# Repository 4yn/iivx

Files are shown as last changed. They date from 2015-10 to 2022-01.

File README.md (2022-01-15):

# iivx

> **Update 2022**
> 
> _Wow_ it's been a while.
> 
> Its been a bit over 6 years (maybe more by the time you're reading this) since I made this controller and the
> build log below. That also means there's that many years worth of newer projects and code out there for building
> music game controllers. Just to make it very clear, **most (if not all) of the code in this repository is outdated**
> and I highly recommend looking at some better/newer resources (code and build logs) if you are planning to try a
> similar project:
>
> - https://consandstuff.github.io/ (active community, especially recommend checking out the discord)
> - https://github.com/knuckleslee/RhythmCodes (will _probably_ work right out of the box)
> - https://rhythm-cons.wiki/w/Controller_Code (general purpose rhythm game controller code)
> - https://github.com/MHeironimus/ArduinoJoystickLibrary/ (general purpose joysticks code
> - https://github.com/speedypotato/Pico-Game-Controller (for the Pi Pico, I personally bought one)
>
> I'm glad that many people have found this repository useful. Keep making cool stuff!

Beatmania IIDX and Sound Voltex hybrid controller running on Arduino Due

Imgur album: http://imgur.com/a/iJoK6

Arduino DUE code targets arduino ver 1.6.4, 1.6.5 onwards added pluggable HID which breaks the SAM libraries

Arduino Leonardo code in /leoo/ targets arduino ver 1.6.8 but should work with versions upward of 1.6.5. /leoo/leoo/ contains code for 9 key + 9 led pnm controller, /leoo/leovx/ contains code for 7 key + 2 lq encoder (<=50ppr) voltex controller, /leoo/leohq/ contains code for 7 key + 2 hq encoder (>=50ppr) volltex controller.

## Variations

For a controller for both Lunatic Rave 2 and K-shoot mania at once (as seen in the youtube video), use a arduino DUE. Download the SAM core with version 1.6.4 and setup as seen in the Software section.

If you rather use a leonardo, you have 3 options:

- Controller with 9 buttons and 9 LEDs as seen in /leoo/leoo/
- Controller with 7 buttons and 2 low quality encoders as seen in /leoo/leovx/
- Controller with 7 buttons and 2 high quality encoders as seen in /leoo/leovxhq/

Just open the .ino file with the latest arudino version and download.

## Hardware

- Beatmania Buttons x9
  - Beatmania layout requires two rows of 3 and 4 vertical keys + 2 utility buttons
  - Voltex layout requires two rows of 4 and 2 (horizontal) keys + 1 utility button
  - Total 9 buttons, top row 3 vertical, middle row 4 vertical and bottom row 2 horizontal
  - [9x White Buttons purchased via Taobao, $10 SGD w/o shipping](https://item.taobao.com/item.htm?spm=a230r.1.14.22.b82vYR&id=15772881563&ns=1&abbucket=2#detail), [(Search Listings)](https://item.taobao.com/item.htm?spm=a230r.1.14.22.b82vYR&id=15772881563&ns=1&abbucket=2#detail)
    - One "button" comes with colored plunger, black main chassis with screw-threaded hollow shaft, accompanying nut for said shaft, extra rectangular housing for padding below, microswitch, microswitch LED saddle/chassis connector, LED housing and spring, all which are detachable
    - Replacing microswitches invloves pulling out microswitch saddle and replacing the microswitch
    - LEDs in the LED saddle may not all be same polarity, be sure to test and reverse LED polarity by pulling out and reinserting LED housing
    - Custom LEDs can also be used by replacing the LED in the housing with your own LEDs
    - LEDs are in theory rated for 12v, but the microcontroller can only supply 3.3v. Be sure to use a transistor or other power supply if you want full brightness.
- Rotary Encoders x3
  - Beatmania layout requires 1 turntable, KOCs use an optical encoder, but a rotary encoder is used here for consistency in purchasing
  - Voltex layout requires 2 knobs for VOL-L and VOL-R control
  - 24ppr encoders should suffice to give a resolution of 96 points per 360 degrees, but higher resolution encoders (300, 600 ppr) are accounted for in this project
  - [3x 600ppr Encoders purchased via Taobao, $25 SGD w/o shipping](http://world.taobao.com/item/16341987368.htm?spm=a312a.7700714.0.0.kKKUs0#detail), [(Search Listings)](http://world.taobao.com/search/search.htm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)
- Microcontroller
  - Arduino DUE used due to:
    - High clock rate
    - Interrupt capability on all pins (other Arduino boards only have 2-4 interrupt pins, insufficient for 4x reading of 3 different rotary encoders which need at least 6 interrupt pins)
    - Native USB functionality, custom HID descriptor is used via modifying core libraries (See Software Section)
  - Purchased a clone from Shenzhen Hua Qiang Bei, $20 SGD\
  - Other clones of DUE board should be readily purchasable online

### Misc Hardware

- Breadboard and jumper wire
- Crimp receptacles
  - Removable connectors which can be plugged in and out of microswitches on buttons
  - Eliminates need to solder directly onto microswitches, microswitches then can be easily replaced
  - One button needs 4 connections, 2 for the LED and 2 for the switch
  - Purchased from hardware store, [similar models here](http://sg.rs-online.com/web/c/connectors/terminals-splices/crimp-receptacles/)
  - Connections were made as such: Microswtich tab >(Crimp receptacle)> 20AUG wire >(soldering connection)> Jumper wire > Breadboard
  - Requires wire strippers, soldering kit and heat shrink tubing
- Logic level converters (if using high-precision encoders)
  - Arduino DUE runs at 3.3v logic, supplying 5v will (possibly) destroy the board
  - High precision encoders require 5v supply in order to function and will output square waves between 5v and 0v, which cannot be directly connected to the board
  - Data wires of each encoder pass through logic level converter to step down voltage, then are connected to the arduino board
  - Low precision encoders (sub 50 ppr) do NOT require a Vcc supply, hence can be read by connecting commmon pin to ground and data pins directly to the arduino board, then enabling the internal pull-up resistors
  - Alternatively just use a 10k and 20k resistor to create a voltage divider for each data wire for the encoder
  - [2x 4-channel Logic Level shifter from Adafruit, $10 SGD w/o shipping](https://www.adafruit.com/products/757)

## Building Materials

- Main mounting plate
  - Comprises
    - Holes for encoder shaft + screw holes to mount encoder
    - Holes for buttons
    - Holes for mounting other plates
  - CAD files are in [/cad/final/](/cad/final/) directory, file name "plate"
- Turntable
  - Round plate with hole in middle to fit rotary encoder shaft
  - Cad files are in /cad/final/ directory, file name "ring"
  - *WARNING: HOLE WAS DRAWN TOO SMALL FOR ENCODER, PLATE REQUIRED EXTRA MACHINING AFTER CNC MANUFACURING, WILL NOT WORK OUT OF THE BOX*
- Knobs
  - Knobs for VOL-L and VOL-R controls
  - [2x Aluminum HIFI Knobs purchased via Taobao, $8 SGD w/o shipping](http://world.taobao.com/item/10341449541.htm?spm=a312a.7700714.0.0.XBrOPF#detail)
  - Uses allen key to tighten, probably a 2-3M one
- Beams
  - Vertical beams to attach all other plates together
  - Similar design to 2020 extrusion for easy mounting of plates vertically
  - 3d printed, files available in [/skp/](/skp/) directory
  - Originally intended to have 6 beams, 3d printer malfunctioned halfway,
- Miscallaneous Plates
  - Extra plates, cut out of 5mm thick foam board. Other materials can be substituted
  - Bottom plate is 430mm x 190mm, with screw holes on four corners
  - Side plates are 398mm x 100mm
  - Cut using jigsaw
- Screws
  - 8x 4M self-tapping screws to attach main plate and bottom plate to beams
  - 9x 3M 12mm screws to mount rotary encoders
- Velcro/Dual-lock tape
  - Attach DUE to bottom plate, but remains detachable

## Assembly

1. Insert button through main plate and lock down with plastic nut
2. Wire buttons to breadboard
3. Screw on rotary encoders
4. Wire encoders to breadboard, including logic level shifter circuit
4. Screw on beams to main plate and then screw on bottom plate
5. Stick breadboard onto bottom plate using adhesive
6. Stick DUE onto bottom plate using velcro tape
7. Detach two beams and insert side plates, then reattach

## Software

The arduino DUE works out of the box with mouse and keyboard functionality, and modifying the USB core libraries allows modifications to how the DUE behaves as a HID object. Modified core library files are found at [/lib/USB/](/lib/usb/), replaces the files located at {APPDATA}\Local\Arduino15\packages\arduino\hardware\sam\1.6.4\cores\arduino\USB. Unmodified files are located at [/lib/USB backup/](/lib/USB%20backup/) to revert to keyboard and mouse functionality. This file implements a custom HID descriptor as well as methods to use said descriptor, allowing the DUE to be recognised as a "Game Pad" with 15 buttons, 3 analog axis and 11 Generic Indicators.

Once the custom USB libraries are installed, open iivx.ino and upload to the DUE.

## Wiring

iivx.ino uses the following pins:

| Item | Pin |
|---|-----|
| **Buttons** | |
| Btn 1 LED | 22  |
| Btn 1 Switch | 23  |
| Btn 2 LED | 24  |
| Btn 2 Switch | 25  |
| ... | ... |
| Btn 9 LED |  38 |
| Btn 9 Switch | 39  |
| **Encoders** | |
| VOL-L Enc Channel A | 46  |
| VOL-L Enc Channel B | 47  |
| VOL-R Enc Channel A | 48  |
| VOL-R Enc Channel B | 49  |
| Turntable Enc Channel A | 50  |
| Turntable Enc Channel B | 51  |

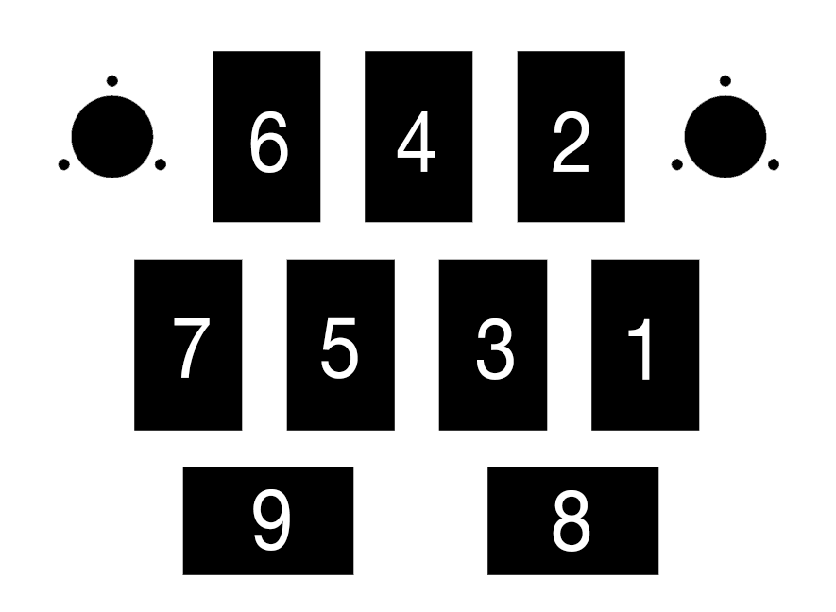
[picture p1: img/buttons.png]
Button Numbers


Button arrangement is up to you and can be changed by modifying the `buttonPins[]` and `ledPins[]` array. If you do change the buttons, be sure to change the constants in lines 178-185 of iivx.ino to correspond to suit your layout.

Getting the encoder arrangement correct is slightly more important. The encoder connected to pins 50 and 51 are given extra functionality in that clockwise and counter-clockwise rotation will trigger button presses on buttons 10 and 11, for use in bindings for Lunatic Rave 2. Additionally, changing the encoder pins requires not only changing the pin numbers in the `#define` lines, but also requires lookup on the exact register of the pin value. Reason being since the program accounts for high-resolution encoders, reading encoder state via digitalRead() has too much overhead which may result in dropped input from either encoder, whereas reading from the pin's memory address is much faster. Pins 64 to 51 all occupy the `PIOC` port on the DUE and the B channels corrsepond to the 16th, 14th and 12th bit of the PIOC memory value.

In order to change the pins the encoders are connected to, look up the exact port and bit that the pin corresponds to [here](http://www.robgray.com/temp/Due-pinout.svg). Change the pin numbers in `#define` as well as the `ENCODER_?_B_REGISTER` values.

## Usage

### Lighting

Press buttons 2, 6, 8 and 9 simultaneously, then finally press button

- 1 to disable LEDs
- 3 to enable reactive lighting, where pressing a button will light the corresponding LED
- 5 to enable HID lighting.

### Lunatic Rave 2

For buttons, bind as normal

For turntable, select turntable-left/right and then twist turntable accordingly

### K-Shoot Mania

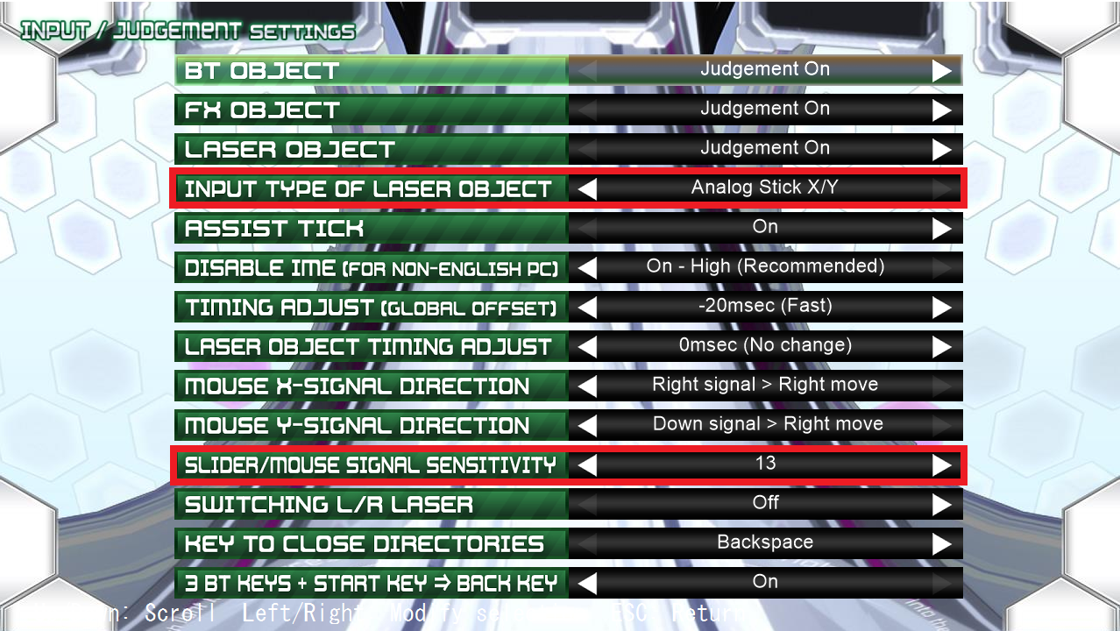
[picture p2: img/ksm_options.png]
KSM Options


Set Input Type to Analog Stick X/Y and set Signal Sensitivity to a high value (>10)

Test KSM play: https://youtu.be/374v2gmAJd4

TODO: In-Program Documentation

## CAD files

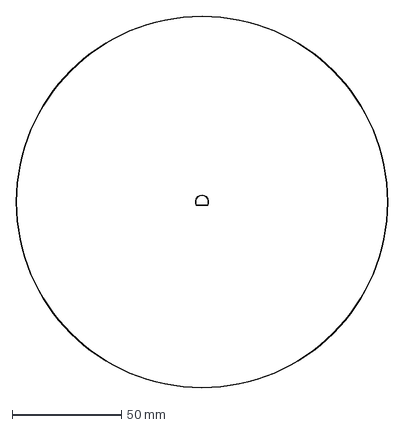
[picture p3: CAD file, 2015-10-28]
cad/final/ring.dxf
170.0 x 170.0 mm

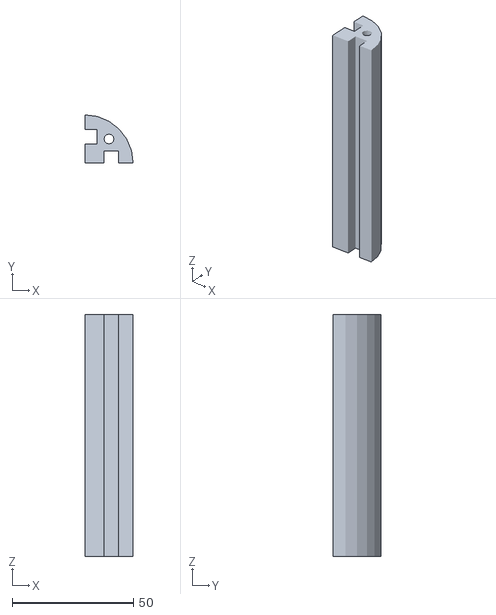
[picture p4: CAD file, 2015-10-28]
skp/edge.stl
20.0 x 20.0 x 100.0

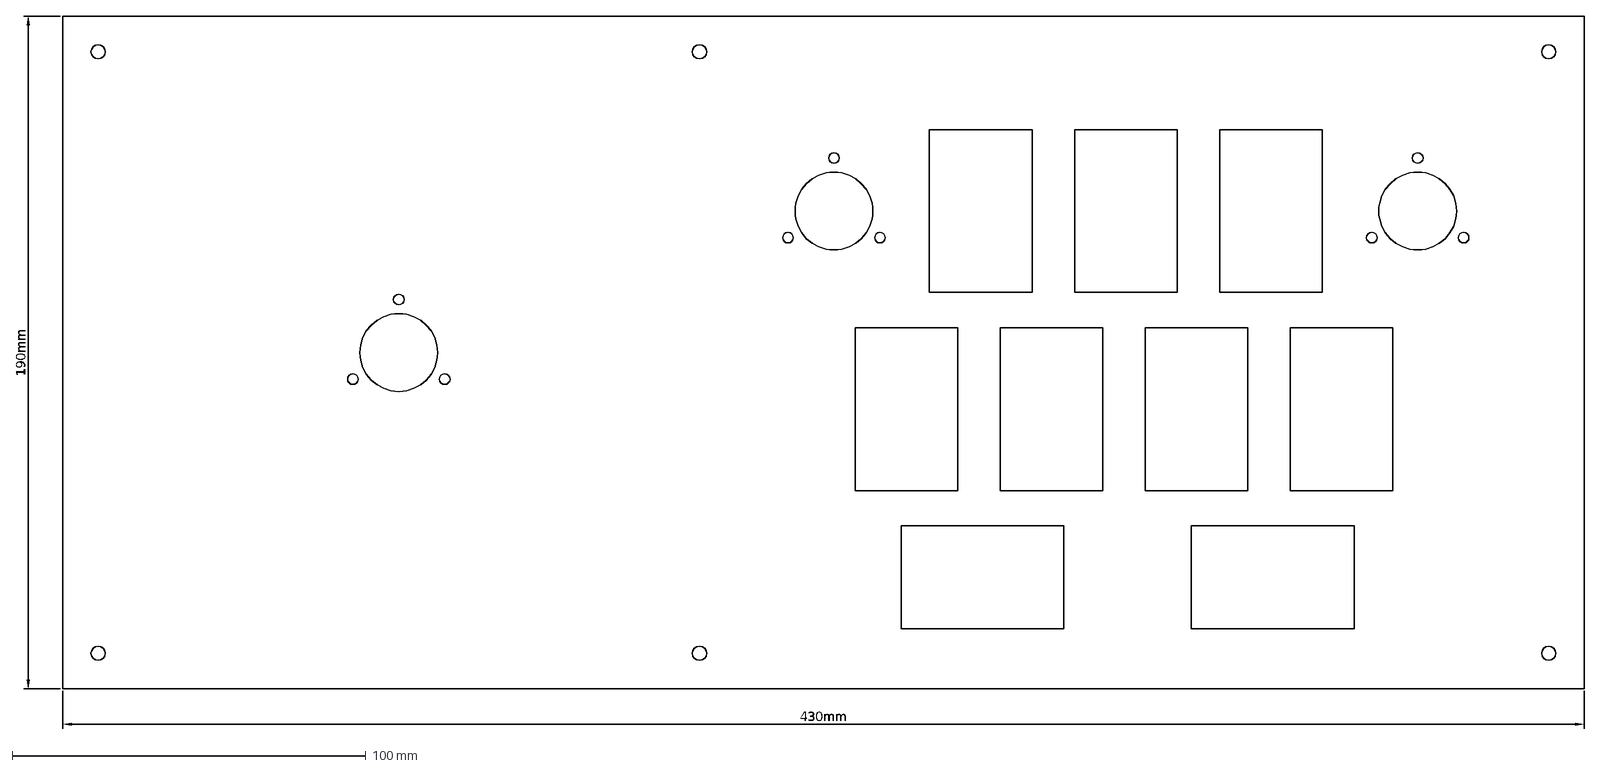
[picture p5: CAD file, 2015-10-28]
cad/final/plate.dxf
190mm
430mm

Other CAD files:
cad/sdvxc2.dwg
cad/sdvxc.dwg
skp/edge.skp

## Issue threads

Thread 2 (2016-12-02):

leovxhq:116: error: expected ')' before ';' token

Espionage724, 2016-12-02:
```
Arduino: 1.6.13 (Windows 10), Board: "Arduino Leonardo"

C:\Users\Espionage724\Desktop\arduino-1.6.13\arduino-builder -dump-prefs -logger=machine -hardware C:\Users\Espionage724\Desktop\arduino-1.6.13\hardware -tools C:\Users\Espionage724\Desktop\arduino-1.6.13\tools-builder -tools C:\Users\Espionage724\Desktop\arduino-1.6.13\hardware\tools\avr -built-in-libraries C:\Users\Espionage724\Desktop\arduino-1.6.13\libraries -libraries C:\Users\Espionage724\Documents\Arduino\libraries -fqbn=arduino:avr:leonardo -vid-pid=0X2341_0X8036 -ide-version=10613 -build-path C:\Users\ESPION~1\AppData\Local\Temp\arduino_build_766418 -warnings=none -prefs=build.warn_data_percentage=75 -prefs=runtime.tools.avr-gcc.path=C:\Users\Espionage724\Desktop\arduino-1.6.13\hardware\tools\avr -prefs=runtime.tools.avrdude.path=C:\Users\Espionage724\Desktop\arduino-1.6.13\hardware\tools\avr -verbose C:\Users\Espionage724\Downloads\iivx-master\leoo\leovxhq\leovxhq.ino
C:\Users\Espionage724\Desktop\arduino-1.6.13\arduino-builder -compile -logger=machine -hardware C:\Users\Espionage724\Desktop\arduino-1.6.13\hardware -tools C:\Users\Espionage724\Desktop\arduino-1.6.13\tools-builder -tools C:\Users\Espionage724\Desktop\arduino-1.6.13\hardware\tools\avr -built-in-libraries C:\Users\Espionage724\Desktop\arduino-1.6.13\libraries -libraries C:\Users\Espionage724\Documents\Arduino\libraries -fqbn=arduino:avr:leonardo -vid-pid=0X2341_0X8036 -ide-version=10613 -build-path C:\Users\ESPION~1\AppData\Local\Temp\arduino_build_766418 -warnings=none -prefs=build.warn_data_percentage=75 -prefs=runtime.tools.avr-gcc.path=C:\Users\Espionage724\Desktop\arduino-1.6.13\hardware\tools\avr -prefs=runtime.tools.avrdude.path=C:\Users\Espionage724\Desktop\arduino-1.6.13\hardware\tools\avr -verbose C:\Users\Espionage724\Downloads\iivx-master\leoo\leovxhq\leovxhq.ino
Using board 'leonardo' from platform in folder: C:\Users\Espionage724\Desktop\arduino-1.6.13\hardware\arduino\avr
Using core 'arduino' from platform in folder: C:\Users\Espionage724\Desktop\arduino-1.6.13\hardware\arduino\avr
Detecting libraries used...
"C:\Users\Espionage724\Desktop\arduino-1.6.13\hardware\tools\avr/bin/avr-g++" -c -g -Os -w -std=gnu++11 -fpermissive -fno-exceptions -ffunction-sections -fdata-sections -fno-threadsafe-statics  -flto -w -x c++ -E -CC -mmcu=atmega32u4 -DF_CPU=16000000L -DARDUINO=10613 -DARDUINO_AVR_LEONARDO -DARDUINO_ARCH_AVR  -DUSB_VID=0x2341 -DUSB_PID=0x8036 '-DUSB_MANUFACTURER="Unknown"' '-DUSB_PRODUCT="Arduino Leonardo"' "-IC:\Users\Espionage724\Desktop\arduino-1.6.13\hardware\arduino\avr\cores\arduino" "-IC:\Users\Espionage724\Desktop\arduino-1.6.13\hardware\arduino\avr\variants\leonardo" "C:\Users\ESPION~1\AppData\Local\Temp\arduino_build_766418\sketch\leovxhq.ino.cpp" -o "nul"
Using cached library dependencies for file: C:\Users\ESPION~1\AppData\Local\Temp\arduino_build_766418\sketch\HID.cpp
Using cached library dependencies for file: C:\Users\ESPION~1\AppData\Local\Temp\arduino_build_766418\sketch\iivx_leo.cpp
Generating function prototypes...
"C:\Users\Espionage724\Desktop\arduino-1.6.13\hardware\tools\avr/bin/avr-g++" -c -g -Os -w -std=gnu++11 -fpermissive -fno-exceptions -ffunction-sections -fdata-sections -fno-threadsafe-statics  -flto -w -x c++ -E -CC -mmcu=atmega32u4 -DF_CPU=16000000L -DARDUINO=10613 -DARDUINO_AVR_LEONARDO -DARDUINO_ARCH_AVR  -DUSB_VID=0x2341 -DUSB_PID=0x8036 '-DUSB_MANUFACTURER="Unknown"' '-DUSB_PRODUCT="Arduino Leonardo"' "-IC:\Users\Espionage724\Desktop\arduino-1.6.13\hardware\arduino\avr\cores\arduino" "-IC:\Users\Espionage724\Desktop\arduino-1.6.13\hardware\arduino\avr\variants\leonardo" "C:\Users\ESPION~1\AppData\Local\Temp\arduino_build_766418\sketch\leovxhq.ino.cpp" -o "C:\Users\ESPION~1\AppData\Local\Temp\arduino_build_766418\preproc\ctags_target_for_gcc_minus_e.cpp"
"C:\Users\Espionage724\Desktop\arduino-1.6.13\tools-builder\ctags\5.8-arduino10/ctags" -u --language-force=c++ -f - --c++-kinds=svpf --fields=KSTtzns --line-directives "C:\Users\ESPION~1\AppData\Local\Temp\arduino_build_766418\preproc\ctags_target_for_gcc_minus_e.cpp"
Compiling sketch...
Using previously compiled file: C:\Users\ESPION~1\AppData\Local\Temp\arduino_build_766418\sketch\HID.cpp.o
Using previously compiled file: C:\Users\ESPION~1\AppData\Local\Temp\arduino_build_766418\sketch\iivx_leo.cpp.o
"C:\Users\Espionage724\Desktop\arduino-1.6.13\hardware\tools\avr/bin/avr-g++" -c -g -Os -w -std=gnu++11 -fpermissive -fno-exceptions -ffunction-sections -fdata-sections -fno-threadsafe-statics -MMD -flto -mmcu=atmega32u4 -DF_CPU=16000000L -DARDUINO=10613 -DARDUINO_AVR_LEONARDO -DARDUINO_ARCH_AVR  -DUSB_VID=0x2341 -DUSB_PID=0x8036 '-DUSB_MANUFACTURER="Unknown"' '-DUSB_PRODUCT="Arduino Leonardo"' "-IC:\Users\Espionage724\Desktop\arduino-1.6.13\hardware\arduino\avr\cores\arduino" "-IC:\Users\Espionage724\Desktop\arduino-1.6.13\hardware\arduino\avr\variants\leonardo" "C:\Users\ESPION~1\AppData\Local\Temp\arduino_build_766418\sketch\leovxhq.ino.cpp" -o "C:\Users\ESPION~1\AppData\Local\Temp\arduino_build_766418\sketch\leovxhq.ino.cpp.o"
C:\Users\Espionage724\Downloads\iivx-master\leoo\leovxhq\leovxhq.ino: In function 'void loop()':

leovxhq:116: error: expected ')' before ';' token

         report.buttons &= ~((uint16_t)1 << (i+buttonCount);

                                                           ^

exit status 1
expected ')' before ';' token
```

4yn, 2016-12-02:
thanks

Closed 2016-12-02.

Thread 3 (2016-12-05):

leovxhq: 'iivxReport_t' does not name a type + Various "not declared in this scope" errors

Espionage724, 2016-12-05:
```
Arduino: 1.6.13 (Windows 7), Board: "Arduino/Genuino Uno"

C:\Users\Espionage724\Downloads\arduino-1.6.13-windows\arduino-1.6.13\arduino-builder -dump-prefs -logger=machine -hardware C:\Users\Espionage724\Downloads\arduino-1.6.13-windows\arduino-1.6.13\hardware -tools C:\Users\Espionage724\Downloads\arduino-1.6.13-windows\arduino-1.6.13\tools-builder -tools C:\Users\Espionage724\Downloads\arduino-1.6.13-windows\arduino-1.6.13\hardware\tools\avr -built-in-libraries C:\Users\Espionage724\Downloads\arduino-1.6.13-windows\arduino-1.6.13\libraries -libraries C:\Users\Espionage724\Documents\Arduino\libraries -fqbn=arduino:avr:uno -vid-pid=0X2341_0X8036 -ide-version=10613 -build-path C:\Users\ESPION~1\AppData\Local\Temp\arduino_build_732012 -warnings=none -prefs=build.warn_data_percentage=75 -prefs=runtime.tools.avrdude.path=C:\Users\Espionage724\Downloads\arduino-1.6.13-windows\arduino-1.6.13\hardware\tools\avr -prefs=runtime.tools.avr-gcc.path=C:\Users\Espionage724\Downloads\arduino-1.6.13-windows\arduino-1.6.13\hardware\tools\avr -verbose C:\Users\Espionage724\Downloads\iivx-master\leoo\leovxhq\leovxhq.ino
C:\Users\Espionage724\Downloads\arduino-1.6.13-windows\arduino-1.6.13\arduino-builder -compile -logger=machine -hardware C:\Users\Espionage724\Downloads\arduino-1.6.13-windows\arduino-1.6.13\hardware -tools C:\Users\Espionage724\Downloads\arduino-1.6.13-windows\arduino-1.6.13\tools-builder -tools C:\Users\Espionage724\Downloads\arduino-1.6.13-windows\arduino-1.6.13\hardware\tools\avr -built-in-libraries C:\Users\Espionage724\Downloads\arduino-1.6.13-windows\arduino-1.6.13\libraries -libraries C:\Users\Espionage724\Documents\Arduino\libraries -fqbn=arduino:avr:uno -vid-pid=0X2341_0X8036 -ide-version=10613 -build-path C:\Users\ESPION~1\AppData\Local\Temp\arduino_build_732012 -warnings=none -prefs=build.warn_data_percentage=75 -prefs=runtime.tools.avrdude.path=C:\Users\Espionage724\Downloads\arduino-1.6.13-windows\arduino-1.6.13\hardware\tools\avr -prefs=runtime.tools.avr-gcc.path=C:\Users\Espionage724\Downloads\arduino-1.6.13-windows\arduino-1.6.13\hardware\tools\avr -verbose C:\Users\Espionage724\Downloads\iivx-master\leoo\leovxhq\leovxhq.ino
Using board 'uno' from platform in folder: C:\Users\Espionage724\Downloads\arduino-1.6.13-windows\arduino-1.6.13\hardware\arduino\avr
Using core 'arduino' from platform in folder: C:\Users\Espionage724\Downloads\arduino-1.6.13-windows\arduino-1.6.13\hardware\arduino\avr
Detecting libraries used...
"C:\Users\Espionage724\Downloads\arduino-1.6.13-windows\arduino-1.6.13\hardware\tools\avr/bin/avr-g++" -c -g -Os -w -std=gnu++11 -fpermissive -fno-exceptions -ffunction-sections -fdata-sections -fno-threadsafe-statics  -flto -w -x c++ -E -CC -mmcu=atmega328p -DF_CPU=16000000L -DARDUINO=10613 -DARDUINO_AVR_UNO -DARDUINO_ARCH_AVR   "-IC:\Users\Espionage724\Downloads\arduino-1.6.13-windows\arduino-1.6.13\hardware\arduino\avr\cores\arduino" "-IC:\Users\Espionage724\Downloads\arduino-1.6.13-windows\arduino-1.6.13\hardware\arduino\avr\variants\standard" "C:\Users\ESPION~1\AppData\Local\Temp\arduino_build_732012\sketch\leovxhq.ino.cpp" -o "nul"
Using cached library dependencies for file: C:\Users\ESPION~1\AppData\Local\Temp\arduino_build_732012\sketch\HID.cpp
Using cached library dependencies for file: C:\Users\ESPION~1\AppData\Local\Temp\arduino_build_732012\sketch\iivx_leo.cpp
Generating function prototypes...
"C:\Users\Espionage724\Downloads\arduino-1.6.13-windows\arduino-1.6.13\hardware\tools\avr/bin/avr-g++" -c -g -Os -w -std=gnu++11 -fpermissive -fno-exceptions -ffunction-sections -fdata-sections -fno-threadsafe-statics  -flto -w -x c++ -E -CC -mmcu=atmega328p -DF_CPU=16000000L -DARDUINO=10613 -DARDUINO_AVR_UNO -DARDUINO_ARCH_AVR   "-IC:\Users\Espionage724\Downloads\arduino-1.6.13-windows\arduino-1.6.13\hardware\arduino\avr\cores\arduino" "-IC:\Users\Espionage724\Downloads\arduino-1.6.13-windows\arduino-1.6.13\hardware\arduino\avr\variants\standard" "C:\Users\ESPION~1\AppData\Local\Temp\arduino_build_732012\sketch\leovxhq.ino.cpp" -o "C:\Users\ESPION~1\AppData\Local\Temp\arduino_build_732012\preproc\ctags_target_for_gcc_minus_e.cpp"
"C:\Users\Espionage724\Downloads\arduino-1.6.13-windows\arduino-1.6.13\tools-builder\ctags\5.8-arduino10/ctags" -u --language-force=c++ -f - --c++-kinds=svpf --fields=KSTtzns --line-directives "C:\Users\ESPION~1\AppData\Local\Temp\arduino_build_732012\preproc\ctags_target_for_gcc_minus_e.cpp"
Compiling sketch...
Using previously compiled file: C:\Users\ESPION~1\AppData\Local\Temp\arduino_build_732012\sketch\HID.cpp.o
Using previously compiled file: C:\Users\ESPION~1\AppData\Local\Temp\arduino_build_732012\sketch\iivx_leo.cpp.o
"C:\Users\Espionage724\Downloads\arduino-1.6.13-windows\arduino-1.6.13\hardware\tools\avr/bin/avr-g++" -c -g -Os -w -std=gnu++11 -fpermissive -fno-exceptions -ffunction-sections -fdata-sections -fno-threadsafe-statics -MMD -flto -mmcu=atmega328p -DF_CPU=16000000L -DARDUINO=10613 -DARDUINO_AVR_UNO -DARDUINO_ARCH_AVR   "-IC:\Users\Espionage724\Downloads\arduino-1.6.13-windows\arduino-1.6.13\hardware\arduino\avr\cores\arduino" "-IC:\Users\Espionage724\Downloads\arduino-1.6.13-windows\arduino-1.6.13\hardware\arduino\avr\variants\standard" "C:\Users\ESPION~1\AppData\Local\Temp\arduino_build_732012\sketch\leovxhq.ino.cpp" -o "C:\Users\ESPION~1\AppData\Local\Temp\arduino_build_732012\sketch\leovxhq.ino.cpp.o"
leovxhq:2: error: 'iivxReport_t' does not name a type

 iivxReport_t report;

 ^

C:\Users\Espionage724\Downloads\iivx-master\leoo\leovxhq\leovxhq.ino: In function 'void loop()':

leovxhq:95: error: 'report' was not declared in this scope

       report.buttons |= (uint16_t)1 << i;

       ^

leovxhq:97: error: 'report' was not declared in this scope

       report.buttons &= ~((uint16_t)1 << i);

       ^

leovxhq:101: error: 'report' was not declared in this scope

   report.xAxis = (uint8_t)((int32_t)(encL / ENCODER_SENSITIVITY) % 256);

   ^

leovxhq:107: error: 'iivx_led' was not declared in this scope

     lights(iivx_led);

            ^

leovxhq:126: error: 'iivx' was not declared in this scope

   iivx.setState(&report);

   ^

exit status 1
'iivxReport_t' does not name a type
```

Espionage724, 2016-12-05:
Had the wrong board selected; no issues with compiling now.

Closed 2016-12-05.

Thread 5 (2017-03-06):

Wiring

croce3, 2017-03-06:
Hello, since i've no idea on how to wire and i fear to make a mess, could you please post a more in-depth wiring diagram?
Thanks in advance.

lizardbeans, 2017-07-20:
Hey, I'm not OP but I'll try to give you some wiring instructions.
From the Arduino there're pins for the buttons signal and for the LEDs energy (in simple words).
Each LED and Button have 2 metal connection points.
One of the is the signal and the other is a ground connection. Ground (a.k.a. common) can be a single wire that connects to each Ground metal connection.

You'll have something like this:

Button Signal     ------ goes to--------> Button pin on the Arduino
Button Ground  ------ goes to---------> Ground pin on the arduino

LED energy  ----------goes to---------> LED pin on the arduino
LED Ground ----------goes to---------> Ground pin on the arduino

You can take multiple grounds and put them together like this:

Button Signal >>> Button Pin 1
LED energy>>>>>LED Pin 1
Button Signal >>> Button Pin 2
LED energy>>>>>LED Pin 2
Button Signal >>> Button Pin 3
LED energy>>>>>LED Pin 3

Button 1 Ground>>>
Button 2 Ground>>>>>>
Button 3 Ground>>>>>>>>>
LED 1 Ground>>>>>>>>>>>>>> A single Ground pin.
LED 2 Ground>>>>>>>>>>>
LED 3 Ground>>>>>>>>

[Like this image](https://sdvxdiy.github.io/Pancake.io_files/switches.JPG)

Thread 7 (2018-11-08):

I got a strange issues？Or a wrong using?

pilldesomebody, 2018-11-08:
Arduino:1.8.7 (Windows 10), 开发板："Arduino Due (Programming Port)"

F:\Arduino\arduino-builder -dump-prefs -logger=machine -hardware F:\Arduino\hardware -hardware C:\Users\Barry zhou\AppData\Local\Arduino15\packages -tools F:\Arduino\tools-builder -tools F:\Arduino\hardware\tools\avr -tools C:\Users\Barry zhou\AppData\Local\Arduino15\packages -built-in-libraries F:\Arduino\libraries -libraries G:\documents\Arduino\libraries -fqbn=arduino:sam:arduino_due_x_dbg -ide-version=10807 -build-path C:\Users\BARRYZ~1\AppData\Local\Temp\arduino_build_538397 -warnings=none -build-cache C:\Users\BARRYZ~1\AppData\Local\Temp\arduino_cache_108794 -prefs=build.warn_data_percentage=75 -prefs=runtime.tools.bossac.path=C:\Users\Barry zhou\AppData\Local\Arduino15\packages\arduino\tools\bossac\1.3-arduino -prefs=runtime.tools.bossac-1.3-arduino.path=C:\Users\Barry zhou\AppData\Local\Arduino15\packages\arduino\tools\bossac\1.3-arduino -prefs=runtime.tools.arm-none-eabi-gcc.path=C:\Users\Barry zhou\AppData\Local\Arduino15\packages\arduino\tools\arm-none-eabi-gcc\4.8.3-2014q1 -prefs=runtime.tools.arm-none-eabi-gcc-4.8.3-2014q1.path=C:\Users\Barry zhou\AppData\Local\Arduino15\packages\arduino\tools\arm-none-eabi-gcc\4.8.3-2014q1 -verbose G:\download\Compressed\iivx\iivx.ino
F:\Arduino\arduino-builder -compile -logger=machine -hardware F:\Arduino\hardware -hardware C:\Users\Barry zhou\AppData\Local\Arduino15\packages -tools F:\Arduino\tools-builder -tools F:\Arduino\hardware\tools\avr -tools C:\Users\Barry zhou\AppData\Local\Arduino15\packages -built-in-libraries F:\Arduino\libraries -libraries G:\documents\Arduino\libraries -fqbn=arduino:sam:arduino_due_x_dbg -ide-version=10807 -build-path C:\Users\BARRYZ~1\AppData\Local\Temp\arduino_build_538397 -warnings=none -build-cache C:\Users\BARRYZ~1\AppData\Local\Temp\arduino_cache_108794 -prefs=build.warn_data_percentage=75 -prefs=runtime.tools.bossac.path=C:\Users\Barry zhou\AppData\Local\Arduino15\packages\arduino\tools\bossac\1.3-arduino -prefs=runtime.tools.bossac-1.3-arduino.path=C:\Users\Barry zhou\AppData\Local\Arduino15\packages\arduino\tools\bossac\1.3-arduino -prefs=runtime.tools.arm-none-eabi-gcc.path=C:\Users\Barry zhou\AppData\Local\Arduino15\packages\arduino\tools\arm-none-eabi-gcc\4.8.3-2014q1 -prefs=runtime.tools.arm-none-eabi-gcc-4.8.3-2014q1.path=C:\Users\Barry zhou\AppData\Local\Arduino15\packages\arduino\tools\arm-none-eabi-gcc\4.8.3-2014q1 -verbose G:\download\Compressed\iivx\iivx.ino
Using board 'arduino_due_x_dbg' from platform in folder: C:\Users\Barry zhou\AppData\Local\Arduino15\packages\arduino\hardware\sam\1.6.4
Using core 'arduino' from platform in folder: C:\Users\Barry zhou\AppData\Local\Arduino15\packages\arduino\hardware\sam\1.6.4
警告：库 SPI 中的分类 '' 不可用。设置为 'Uncategorized'
警告：库 Wire 中的分类 '' 不可用。设置为 'Uncategorized'
构建选项已变更，全部重新构建
警告：核心 'Arduino ARM (32-bits) Boards' 中的 platform.txt 文件 包含已废弃的 recipe.c.combine.pattern="{compiler.path}{compiler.c.elf.cmd}" {compiler.c.elf.flags} -mcpu={build.mcu} "-T{build.variant.path}/{build.ldscript}" "-Wl,-Map,{build.path}/{build.project_name}.map" {compiler.c.elf.extra_flags} -o "{build.path}/{build.project_name}.elf" "-L{build.path}" -mthumb -Wl,--cref -Wl,--check-sections -Wl,--gc-sections -Wl,--entry=Reset_Handler -Wl,--unresolved-symbols=report-all -Wl,--warn-common -Wl,--warn-section-align -Wl,--warn-unresolved-symbols -Wl,--start-group "{build.path}/syscalls_sam3.c.o" {object_files} "{build.variant.path}/{build.variant_system_lib}" "{build.path}/{archive_file}" -Wl,--end-group -lm -gcc，已自动转换为 recipe.c.combine.pattern="{compiler.path}{compiler.c.elf.cmd}" {compiler.c.elf.flags} -mcpu={build.mcu} "-T{build.variant.path}/{build.ldscript}" "-Wl,-Map,{build.path}/{build.project_name}.map" {compiler.c.elf.extra_flags} -o "{build.path}/{build.project_name}.elf" "-L{build.path}" -mthumb -Wl,--cref -Wl,--check-sections -Wl,--gc-sections -Wl,--entry=Reset_Handler -Wl,--unresolved-symbols=report-all -Wl,--warn-common -Wl,--warn-section-align -Wl,--warn-unresolved-symbols -Wl,--start-group "{build.path}/core/syscalls_sam3.c.o" {object_files} "{build.variant.path}/{build.variant_system_lib}" "{build.path}/{archive_file}" -Wl,--end-group -lm -gcc。请考虑更新核心。
警告：核心 'Arduino ARM (32-bits) Boards' 中的 platform.txt 文件 包含已废弃的 recipe.ar.pattern="{compiler.path}{compiler.ar.cmd}" {compiler.ar.flags} {compiler.ar.extra_flags} "{build.path}/{archive_file}" "{object_file}"，已自动转换为 recipe.ar.pattern="{compiler.path}{compiler.ar.cmd}" {compiler.ar.flags} {compiler.ar.extra_flags} "{archive_file_path}" "{object_file}"。请考虑更新核心。
Detecting libraries used...
"C:\\Users\\Barry zhou\\AppData\\Local\\Arduino15\\packages\\arduino\\tools\\arm-none-eabi-gcc\\4.8.3-2014q1/bin/arm-none-eabi-g++" -c -g -Os -w -ffunction-sections -fdata-sections -nostdlib -fno-threadsafe-statics --param max-inline-insns-single=500 -fno-rtti -fno-exceptions -Dprintf=iprintf -w -x c++ -E -CC -mcpu=cortex-m3 -DF_CPU=84000000L -DARDUINO=10807 -DARDUINO_SAM_DUE -DARDUINO_ARCH_SAM -D__SAM3X8E__ -mthumb -DUSB_VID=0x2341 -DUSB_PID=0x003e -DUSBCON "-DUSB_MANUFACTURER=\"Unknown\"" "-DUSB_PRODUCT=\"Arduino Due\"" "-IC:\\Users\\Barry zhou\\AppData\\Local\\Arduino15\\packages\\arduino\\hardware\\sam\\1.6.4\\system/libsam" "-IC:\\Users\\Barry zhou\\AppData\\Local\\Arduino15\\packages\\arduino\\hardware\\sam\\1.6.4\\system/CMSIS/CMSIS/Include/" "-IC:\\Users\\Barry zhou\\AppData\\Local\\Arduino15\\packages\\arduino\\hardware\\sam\\1.6.4\\system/CMSIS/Device/ATMEL/" "-IC:\\Users\\Barry zhou\\AppData\\Local\\Arduino15\\packages\\arduino\\hardware\\sam\\1.6.4\\cores\\arduino" "-IC:\\Users\\Barry zhou\\AppData\\Local\\Arduino15\\packages\\arduino\\hardware\\sam\\1.6.4\\variants\\arduino_due_x" "C:\\Users\\BARRYZ~1\\AppData\\Local\\Temp\\arduino_build_538397\\sketch\\iivx.ino.cpp" -o nul
Generating function prototypes...
"C:\\Users\\Barry zhou\\AppData\\Local\\Arduino15\\packages\\arduino\\tools\\arm-none-eabi-gcc\\4.8.3-2014q1/bin/arm-none-eabi-g++" -c -g -Os -w -ffunction-sections -fdata-sections -nostdlib -fno-threadsafe-statics --param max-inline-insns-single=500 -fno-rtti -fno-exceptions -Dprintf=iprintf -w -x c++ -E -CC -mcpu=cortex-m3 -DF_CPU=84000000L -DARDUINO=10807 -DARDUINO_SAM_DUE -DARDUINO_ARCH_SAM -D__SAM3X8E__ -mthumb -DUSB_VID=0x2341 -DUSB_PID=0x003e -DUSBCON "-DUSB_MANUFACTURER=\"Unknown\"" "-DUSB_PRODUCT=\"Arduino Due\"" "-IC:\\Users\\Barry zhou\\AppData\\Local\\Arduino15\\packages\\arduino\\hardware\\sam\\1.6.4\\system/libsam" "-IC:\\Users\\Barry zhou\\AppData\\Local\\Arduino15\\packages\\arduino\\hardware\\sam\\1.6.4\\system/CMSIS/CMSIS/Include/" "-IC:\\Users\\Barry zhou\\AppData\\Local\\Arduino15\\packages\\arduino\\hardware\\sam\\1.6.4\\system/CMSIS/Device/ATMEL/" "-IC:\\Users\\Barry zhou\\AppData\\Local\\Arduino15\\packages\\arduino\\hardware\\sam\\1.6.4\\cores\\arduino" "-IC:\\Users\\Barry zhou\\AppData\\Local\\Arduino15\\packages\\arduino\\hardware\\sam\\1.6.4\\variants\\arduino_due_x" "C:\\Users\\BARRYZ~1\\AppData\\Local\\Temp\\arduino_build_538397\\sketch\\iivx.ino.cpp" -o "C:\\Users\\BARRYZ~1\\AppData\\Local\\Temp\\arduino_build_538397\\preproc\\ctags_target_for_gcc_minus_e.cpp"
"F:\\Arduino\\tools-builder\\ctags\\5.8-arduino11/ctags" -u --language-force=c++ -f - --c++-kinds=svpf --fields=KSTtzns --line-directives "C:\\Users\\BARRYZ~1\\AppData\\Local\\Temp\\arduino_build_538397\\preproc\\ctags_target_for_gcc_minus_e.cpp"
正在编译项目...
"C:\\Users\\Barry zhou\\AppData\\Local\\Arduino15\\packages\\arduino\\tools\\arm-none-eabi-gcc\\4.8.3-2014q1/bin/arm-none-eabi-g++" -c -g -Os -w -ffunction-sections -fdata-sections -nostdlib -fno-threadsafe-statics --param max-inline-insns-single=500 -fno-rtti -fno-exceptions -Dprintf=iprintf -MMD -mcpu=cortex-m3 -DF_CPU=84000000L -DARDUINO=10807 -DARDUINO_SAM_DUE -DARDUINO_ARCH_SAM -D__SAM3X8E__ -mthumb -DUSB_VID=0x2341 -DUSB_PID=0x003e -DUSBCON "-DUSB_MANUFACTURER=\"Unknown\"" "-DUSB_PRODUCT=\"Arduino Due\"" "-IC:\\Users\\Barry zhou\\AppData\\Local\\Arduino15\\packages\\arduino\\hardware\\sam\\1.6.4\\system/libsam" "-IC:\\Users\\Barry zhou\\AppData\\Local\\Arduino15\\packages\\arduino\\hardware\\sam\\1.6.4\\system/CMSIS/CMSIS/Include/" "-IC:\\Users\\Barry zhou\\AppData\\Local\\Arduino15\\packages\\arduino\\hardware\\sam\\1.6.4\\system/CMSIS/Device/ATMEL/" "-IC:\\Users\\Barry zhou\\AppData\\Local\\Arduino15\\packages\\arduino\\hardware\\sam\\1.6.4\\cores\\arduino" "-IC:\\Users\\Barry zhou\\AppData\\Local\\Arduino15\\packages\\arduino\\hardware\\sam\\1.6.4\\variants\\arduino_due_x" "C:\\Users\\BARRYZ~1\\AppData\\Local\\Temp\\arduino_build_538397\\sketch\\iivx.ino.cpp" -o "C:\\Users\\BARRYZ~1\\AppData\\Local\\Temp\\arduino_build_538397\\sketch\\iivx.ino.cpp.o"
Compiling libraries...
Compiling core...
"C:\\Users\\Barry zhou\\AppData\\Local\\Arduino15\\packages\\arduino\\tools\\arm-none-eabi-gcc\\4.8.3-2014q1/bin/arm-none-eabi-g++" -c -g -Os -w -ffunction-sections -fdata-sections -nostdlib -fno-threadsafe-statics --param max-inline-insns-single=500 -fno-rtti -fno-exceptions -Dprintf=iprintf -MMD -mcpu=cortex-m3 -DF_CPU=84000000L -DARDUINO=10807 -DARDUINO_SAM_DUE -DARDUINO_ARCH_SAM -D__SAM3X8E__ -mthumb -DUSB_VID=0x2341 -DUSB_PID=0x003e -DUSBCON "-DUSB_MANUFACTURER=\"Unknown\"" "-DUSB_PRODUCT=\"Arduino Due\"" "-IC:\\Users\\Barry zhou\\AppData\\Local\\Arduino15\\packages\\arduino\\hardware\\sam\\1.6.4\\system/libsam" "-IC:\\Users\\Barry zhou\\AppData\\Local\\Arduino15\\packages\\arduino\\hardware\\sam\\1.6.4\\system/CMSIS/CMSIS/Include/" "-IC:\\Users\\Barry zhou\\AppData\\Local\\Arduino15\\packages\\arduino\\hardware\\sam\\1.6.4\\system/CMSIS/Device/ATMEL/" "-IC:\\Users\\Barry zhou\\AppData\\Local\\Arduino15\\packages\\arduino\\hardware\\sam\\1.6.4\\cores\\arduino" "-IC:\\Users\\Barry zhou\\AppData\\Local\\Arduino15\\packages\\arduino\\hardware\\sam\\1.6.4\\variants\\arduino_due_x" "C:\\Users\\Barry zhou\\AppData\\Local\\Arduino15\\packages\\arduino\\hardware\\sam\\1.6.4\\variants\\arduino_due_x\\variant.cpp" -o "C:\\Users\\BARRYZ~1\\AppData\\Local\\Temp\\arduino_build_538397\\core\\variant.cpp.o"
"C:\\Users\\Barry zhou\\AppData\\Local\\Arduino15\\packages\\arduino\\tools\\arm-none-eabi-gcc\\4.8.3-2014q1/bin/arm-none-eabi-gcc" -c -g -Os -w -ffunction-sections -fdata-sections -nostdlib --param max-inline-insns-single=500 -Dprintf=iprintf -MMD -mcpu=cortex-m3 -DF_CPU=84000000L -DARDUINO=10807 -DARDUINO_SAM_DUE -DARDUINO_ARCH_SAM -D__SAM3X8E__ -mthumb -DUSB_VID=0x2341 -DUSB_PID=0x003e -DUSBCON "-DUSB_MANUFACTURER=\"Unknown\"" "-DUSB_PRODUCT=\"Arduino Due\"" "-IC:\\Users\\Barry zhou\\AppData\\Local\\Arduino15\\packages\\arduino\\hardware\\sam\\1.6.4\\system/libsam" "-IC:\\Users\\Barry zhou\\AppData\\Local\\Arduino15\\packages\\arduino\\hardware\\sam\\1.6.4\\system/CMSIS/CMSIS/Include/" "-IC:\\Users\\Barry zhou\\AppData\\Local\\Arduino15\\packages\\arduino\\hardware\\sam\\1.6.4\\system/CMSIS/Device/ATMEL/" "-IC:\\Users\\Barry zhou\\AppData\\Local\\Arduino15\\packages\\arduino\\hardware\\sam\\1.6.4\\cores\\arduino" "-IC:\\Users\\Barry zhou\\AppData\\Local\\Arduino15\\packages\\arduino\\hardware\\sam\\1.6.4\\variants\\arduino_due_x" "C:\\Users\\Barry zhou\\AppData\\Local\\Arduino15\\packages\\arduino\\hardware\\sam\\1.6.4\\cores\\arduino\\syscalls_sam3.c" -o "C:\\Users\\BARRYZ~1\\AppData\\Local\\Temp\\arduino_build_538397\\core\\syscalls_sam3.c.o"
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

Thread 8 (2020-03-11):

How do I wire the rotary encoders?

Swarsele, 2020-03-11:
Hello,

I wanted to ask if you could post a picture of your wiring of the rotary encoders - mine have 4 wires as well as one "big" strain of wire that I have never seen anywhere else before (I am not too well versed). Now I do not know how I should wire them to the logic boards. Any help is appreciated :)

Greets

4yn, 2020-03-11:
Usually its black to ground, red to 3v or 5v (check your rotary encoder model) and the last 2 to the data pins.

Swarsele, 2020-03-11:
Thank you for the extremely fast response!

I have done more research, it seems the "weird" strain of wire is the "shielding wire" (that big silvery one). Do I just connect it to GND as well? My rotary encoder has these cables:
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

In the attachment I have put a sketch of how I think I should connect the due and encoder to the LLC, would that be correct? Excuse the ugly sketch, I do not know how to make a proper circuit diagram. (the same method I would then use for the other two encoders too, since I used 600ppr for all three as well)

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

In my mind, it seems wrong to simply short the 0V and Shielding wire of the encoder together to GND, but I do not know where else I should connect the shielding wire to.

Once again, thank you for replying so fast. I am honored :)

4yn, 2020-03-11:
Yeah just short it to ground, doesn't matter which side of the LLC you connect it to both are the same

Swarsele, 2020-03-11:
Nice! I will try it out soon :) Thank you for an amazing project!

By the way, I designed a piece for 3D printing that can use the holes in the middle of the plate - might be useful for people like me that went with 3mm acrylic and want a little bit more stability in their build. I also added the possibility to put another wall through the middle, although that will possibly be quite fiddly with the wiring then... feel free to add it to the project if you like
 - it should fit to the edge.stl you provided :)

All the best!

[iivx side.zip](https://github.com/4yn/iivx/files/4321584/iivx.side.zip)

Closed 2020-03-11.

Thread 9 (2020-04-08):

Using with KSM (and possibly others)

Swarsele, 2020-04-08:
Hey again :)
I have finally finished the build! However, I am having a hard time getting the controller to work in KSM (and probably in other games as well)
I cannot manage to setup the keys within the game; as soon as I change the key bindings for one of the 4 main keys, the interface stops responding until I delete the binding again... the keys themselves are recognized however, so I am mostly asking how you managed to get it setup.

Also, the VOL-L/R keys are behaving strangely. Turning the knob in one direction moves the slider in the other direction :/ I tried switching the A and B data pins, but that did not help ... what could be the issue?

Thank you again for an awesome build!!

4yn, 2020-04-08:
Regarding the keybindings, I'm sorry but im not in much of a place to help. KSM might have changed their input library and i've since decommissioned my original build so its hard for me to test on my side either. Maybe try with an older KSM version?

Swapping the A and B pins definitely should work. For a sanity check maybe swap the pin IDs (the `#DEFINE ENCODER_X_A <number>` parts) and see if it changes anything. I've also found the windows game controller properties menu (control panel > devices and printers > right click on the entry with the arduino > ??? just look around) useful for debugging if the axis seems to be off.

Debugging over github is hard btw, throw me a pm over discord (4yn#4098) and I'll see if i can get to you faster there.

4yn, 2020-04-10:
OK time to do some wrap-up stack overflow style

For the button issue, the original setup uses the NC and GND pins of each microswitch. If you are facing issues with mapping buttons, check the windows game controller menus and see if all the buttons look pressed. If yes, change [this line](https://github.com/4yn/iivx/blob/master/iivx.ino#L130) to `LOW` and you should be peachy.

For the encoders... uh just try flipping them in software too. He solved the issue before I could get to him.

Closed 2020-04-10.

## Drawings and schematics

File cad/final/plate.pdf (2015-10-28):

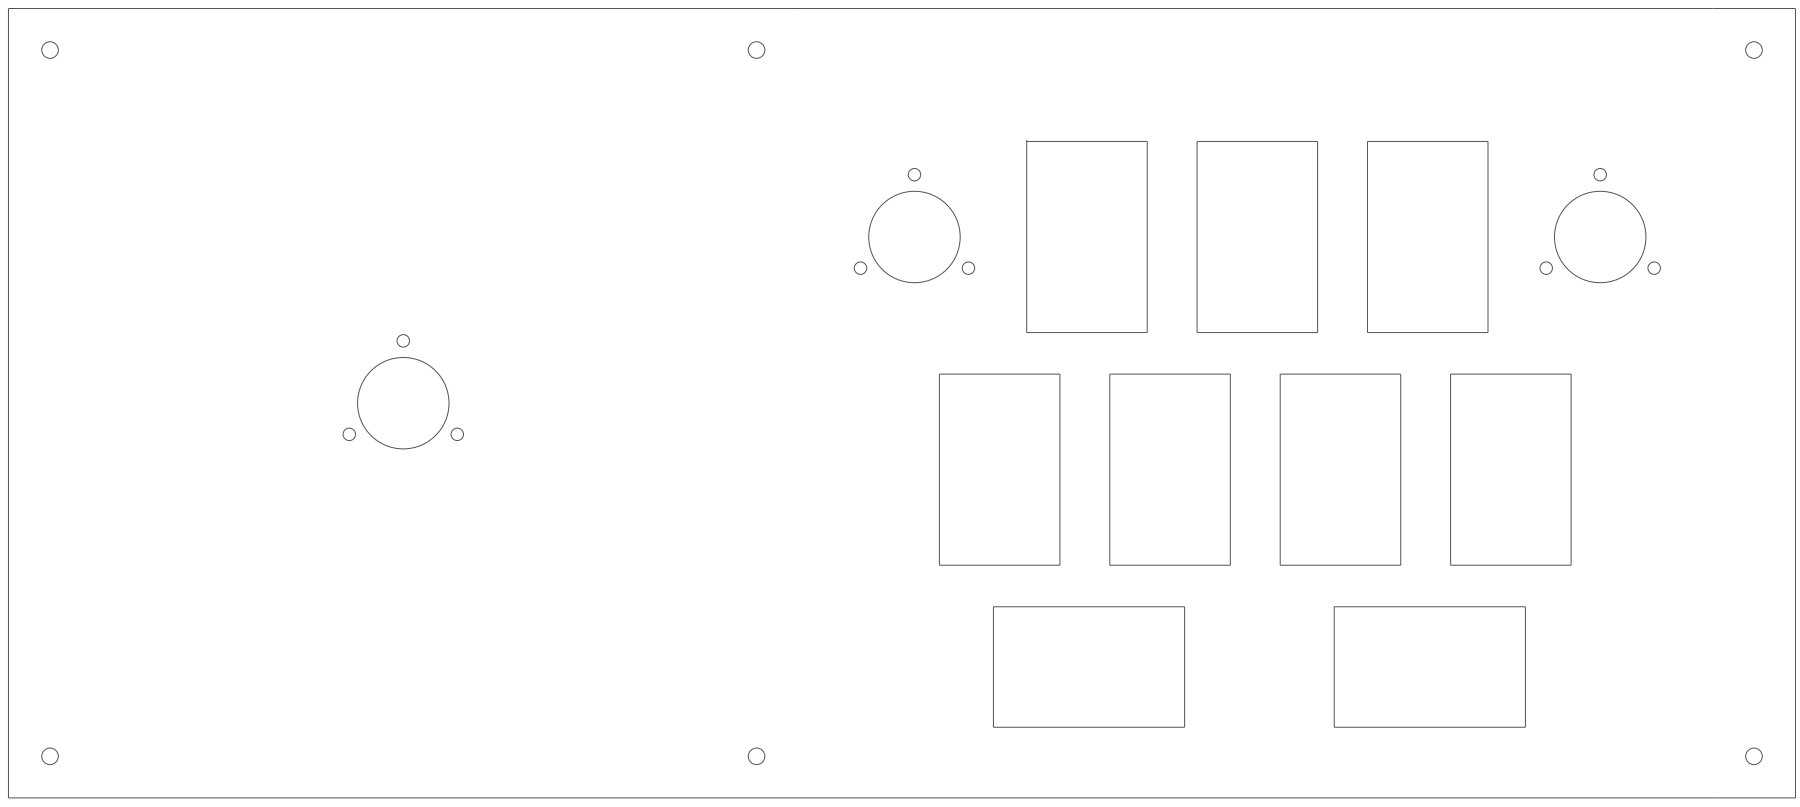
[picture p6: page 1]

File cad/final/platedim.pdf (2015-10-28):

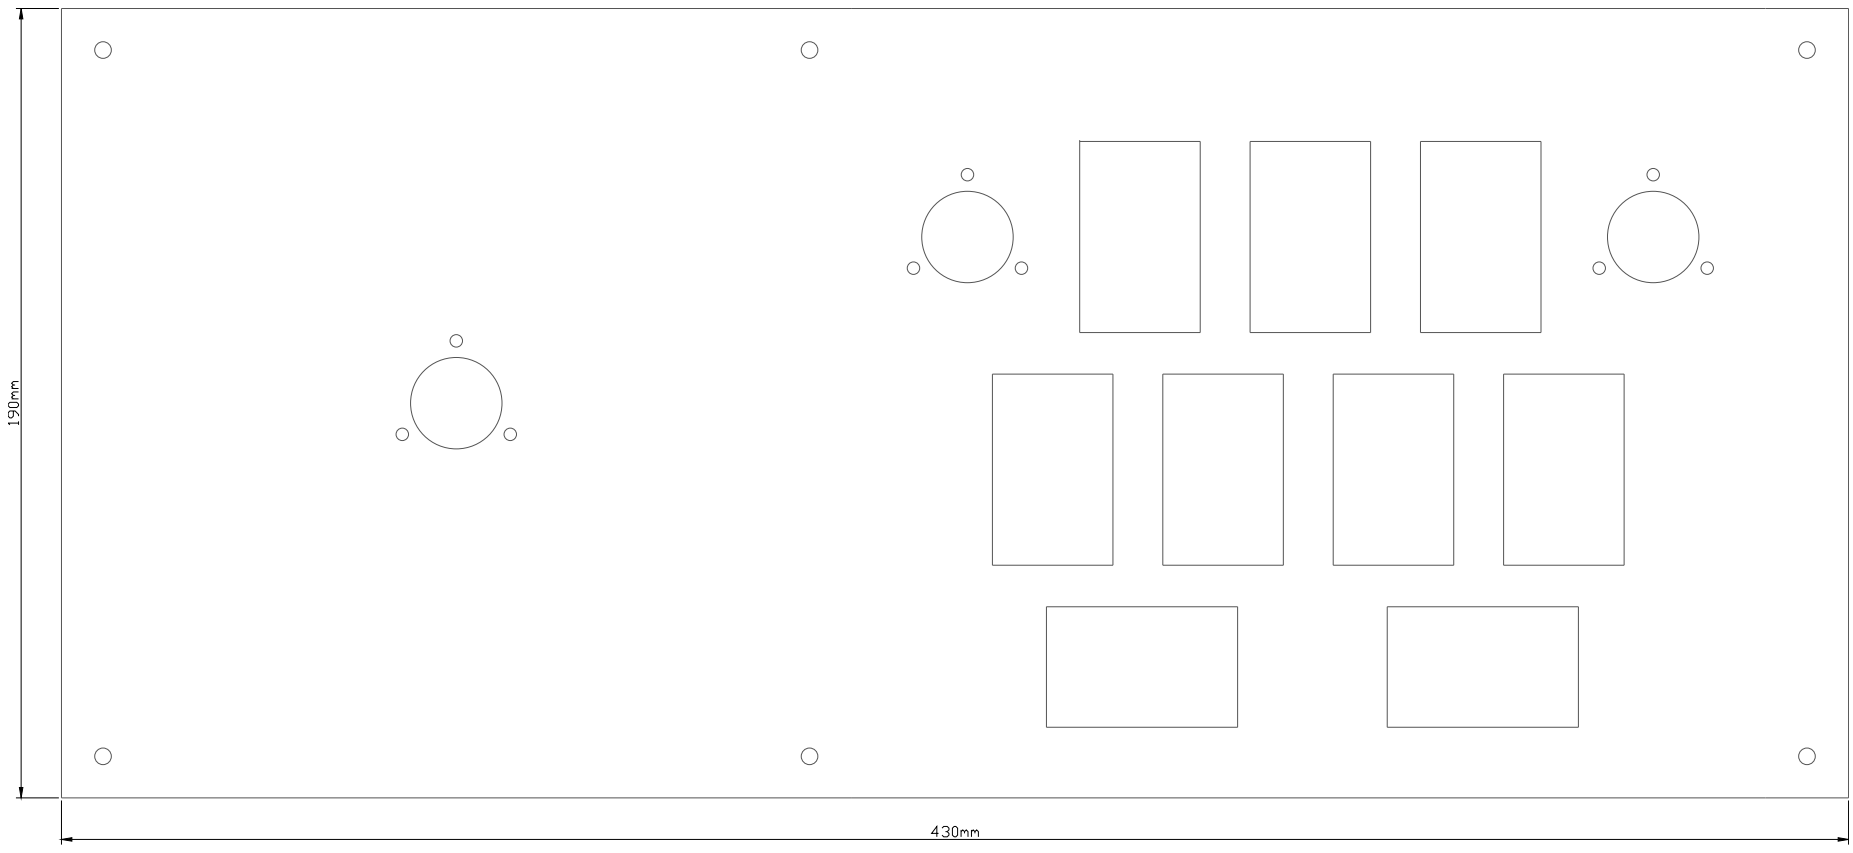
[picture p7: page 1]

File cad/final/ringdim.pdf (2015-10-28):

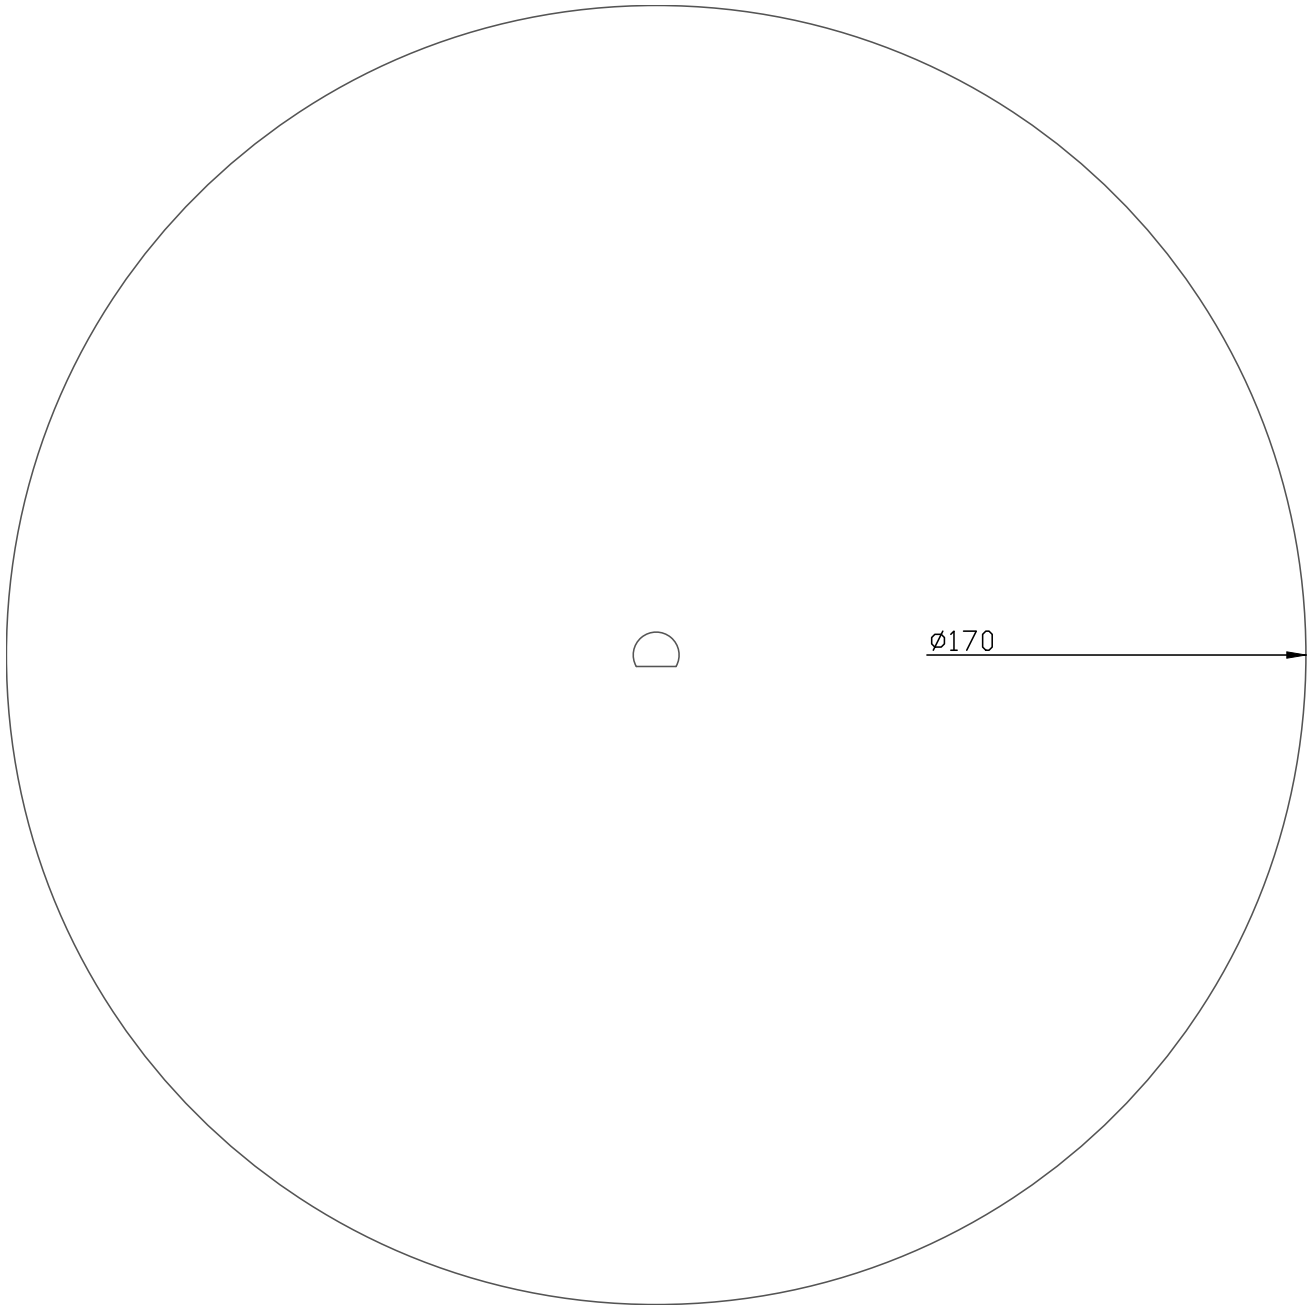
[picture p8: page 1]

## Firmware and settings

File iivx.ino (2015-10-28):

/* 
 * IIVX
 *  
 * Beatmania IIDX + Sound Voltex hybrid controller
 * 9 buttons, 2 knobs, 1 turntable (forward + backward movement mapped to buttons 10 and 11)
 * Using Arduino Due
 * 
 * Use "Slider" mode in KSM for knobs to work
 * 
 */

// Microseconds to wait between loops: 0 delay gives 4000 reports a second, 2000 gives 250 reports a second
#define REPORT_DELAY 2000 
// Toggle debug mode: 0 = Disable serial debug, 1 = Enable, 2 = Verbose Output
#define DEBUG_ENABLE 0

// Button Pins
uint8_t buttonCount = 9; //Maximum 15
uint8_t buttonPins[] = {23,25,27,29,31,33,35,37,39}; // Array of buttons
uint8_t ledPins[] = {22,24,26,28,30,32,34,36,38}; // Array of LEDs

// Encoder Pins
// All encoder pins are set on the DUE's C port
// Pin mapping is used to speed up encoder processing, especially for high-performance encoders
// Why did I get the 600 p/r ones
#define ENCODER_SENSITIVITY (double) 2.34375 // I'm using 600 ppr encoders at 1x resolution while HID reports 256 data points per rotation, 600/256 = 2.34375
#define ENCODER_PINPORT PIOC
#define ENCODER_X_A 46
#define ENCODER_X_B 47
#define ENCODER_X_B_REGISTER 16
#define ENCODER_Y_A 48
#define ENCODER_Y_B 49
#define ENCODER_Y_B_REGISTER 14
#define ENCODER_Z_A 50
#define ENCODER_Z_B 51
#define ENCODER_Z_B_REGISTER 12
#define ENCODER_Z_MILLIS_TOLERANCE 100 // Amount of miliseconds to wait and change state of turntable buttons

// System Variables
uint8_t lighting = 0; // Storage for current lighting mode: 0: Lights off, 1: Reactive Lights, 2: HID Lights Press buttons 2, 6, 8 and 9 to enable set, then press 1 for off, 3 for reactive and 5 for HID lights
iivxReport_t report; // Storage for button and knob states
uint16_t hidLed; // Storage for HID led state
volatile int32_t encX = 0, encY = 0, encZ = 0, encZlast = 0, encZmillis = 0; // Storage for encoder states

// Encoder Processing
// Using direct port reading due to large overhead of digitalRead, speeds up especially in case of high resolution encoders
void encXProc(){
  if(bitRead(ENCODER_PINPORT -> PIO_PDSR,ENCODER_X_B_REGISTER)){
    encX -= 1;
  } else {
    encX += 1;
  }
}
void encYProc(){
  if(bitRead(ENCODER_PINPORT -> PIO_PDSR,ENCODER_Y_B_REGISTER)){
    encY -= 1;
  } else {
    encY += 1;
  }
}
void encZProc(){
  if(bitRead(ENCODER_PINPORT -> PIO_PDSR,ENCODER_Z_B_REGISTER)){
    encZ -= 1;
  } else {
    encZ += 1;
  }
}

// Lighting Processing
void lights(uint16_t l){
  for(int i=0;i<buttonCount;i++){
     if(bitRead(l,i)){
         digitalWrite(ledPins[i],HIGH);
     } else {
         digitalWrite(ledPins[i],LOW);
     }
   }
}

void setup() {

  delay(1000);
  
  if(DEBUG_ENABLE) SerialUSB.begin(9600);
  
  // Pinmode Setup
  
  if(DEBUG_ENABLE) SerialUSB.println("Begin Setup");

  // Button Pinmode
  for(int i=0;i<buttonCount;i++){ // Loop for each set of LED and button
    pinMode(buttonPins[i],INPUT); // Set button pin to output
    digitalWrite(buttonPins[i],HIGH); // Enable pullup resistor on button pins
    pinMode(ledPins[i],OUTPUT); // Set led pin to output
  }

  // Encoder Pinmode
  pinMode(ENCODER_X_A,INPUT);
  pinMode(ENCODER_X_B,INPUT);
  pinMode(ENCODER_Y_A,INPUT);
  pinMode(ENCODER_Y_B,INPUT);
  pinMode(ENCODER_Z_A,INPUT);
  pinMode(ENCODER_Z_B,INPUT);
  // Encoder Pullup
  digitalWrite(ENCODER_X_A,HIGH);
  digitalWrite(ENCODER_X_B,HIGH);
  digitalWrite(ENCODER_Y_A,HIGH);
  digitalWrite(ENCODER_Y_B,HIGH);
  digitalWrite(ENCODER_Z_A,HIGH);
  digitalWrite(ENCODER_Z_B,HIGH);

  // Encoder Interrupt Setup

  attachInterrupt(ENCODER_X_A,encXProc,RISING);
  attachInterrupt(ENCODER_Y_A,encYProc,RISING);
  attachInterrupt(ENCODER_Z_A,encZProc,RISING);

  // Reset Lights
  lights(0);
  
}

void loop() {

  if(DEBUG_ENABLE) SerialUSB.println("Begin Loop");

  // Read buttons
  
  for(int i=0;i<buttonCount;i++){ // Loop for each button
    if(digitalRead(buttonPins[i])==HIGH){ //Button pressed
      report.buttons |= (uint16_t)1 << i; // Set i'th bit to 1
    } else {
      report.buttons &= ~((uint16_t)1 << i); // Set i'th bit to 0;
    }
  }

  // Read Encoders
  report.xAxis = (uint8_t)((int32_t)(encX / ENCODER_SENSITIVITY) % 256);
  report.yAxis = (uint8_t)((int32_t)(encY / ENCODER_SENSITIVITY) % 256);
  report.zAxis = (uint8_t)((int32_t)(encZ / ENCODER_SENSITIVITY) % 256);

  // Read turntable buttons
  if( (int32_t)(encZ / ENCODER_SENSITIVITY) - encZlast > 5) {
    if(millis() - encZmillis > ENCODER_Z_MILLIS_TOLERANCE || bitRead(report.buttons,9)) {
      report.buttons |= (uint16_t)1 << 9;
      report.buttons &= ~((uint16_t)1 << 10);
      encZlast = (encZ / ENCODER_SENSITIVITY);
      encZmillis = millis();
    }
  } else if ( (int32_t)(encZ / ENCODER_SENSITIVITY) - encZlast < -5){
    if(millis() - encZmillis > ENCODER_Z_MILLIS_TOLERANCE || bitRead(report.buttons,10)) {
      report.buttons |= (uint16_t)1 << 10;
      report.buttons &= ~((uint16_t)1 << 9);
      encZlast = (encZ / ENCODER_SENSITIVITY);
      encZmillis = millis();
    }
  } else {
    if(millis() - encZmillis > ENCODER_Z_MILLIS_TOLERANCE) {
      report.buttons &= ~((uint16_t)1 << 9);
      report.buttons &= ~((uint16_t)1 << 10);
    }
  }
  
  if(DEBUG_ENABLE) SerialUSB.println(encZlast);
  if(DEBUG_ENABLE) SerialUSB.println(report.xAxis);

  // Write LED states
  if(lighting){
    if(lighting==1){
      lights(report.buttons);
    } else if (lighting==2){
      hidLed = iivx.readState();
      lights(hidLed);
    }
  }

  // Check if setting lighting mode
  if(report.buttons==419){
    lighting = 0;
    lights(0);
  } else if (report.buttons==422){
    lighting =  1;
  } else if (report.buttons==434){
    lighting = 2;
  }

  // Wrap-up

  iivx.setState(&report);
  
  delayMicroseconds(REPORT_DELAY); // Delay to reduce report rate
}

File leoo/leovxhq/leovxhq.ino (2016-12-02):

#include "iivx_leo.h"
iivxReport_t report; 

#define REPORT_DELAY 2000
// Number of microseconds between HID reports
// 2000 = 500hz

#define ENC_L_A 0
#define ENC_L_B 1
#define ENC_L_B_ADDR 3
#define ENC_R_A 2
#define ENC_R_B 3
#define ENC_R_B_ADDR 0
#define ENCODER_SENSITIVITY (double) 1.5625
#define ENCODER_PORT PIND
// encoder sensitivity = number of positions per rotation (400) / number of positions for HID report (256)
/*
 * connect encoders
 * VOL-L to pins 0 and 1
 * VOL-R to pins 2 and 3
 */

int tmp;
uint8_t buttonCount = 7;
uint8_t lightMode = 1;
// 0 = reactive lighting, 1 = HID lighting
uint8_t ledPins[] = {6,7,8,9,10,11,12};
uint8_t buttonPins[] = {13,18,19,20,21,22,23};
uint8_t sysPin = 5;
uint8_t reactiveLightPin = 21;
uint8_t hidLightPin = 22;
uint8_t sysInputPins[] = {13,18,19,20};
int32_t encL=0, encR=0;
/* current pin layout
 *  pins 6 to 12 = LED 1 to 7
 *    connect pin to + termnial of LED
 *    connect ground to resistor and then - terminal of LED
 *  pins 13, A0 to A5 = Button input 1 to 7
 *    connect button pin to ground to trigger button press
 *  pins 5 = system pin
 *    connect system pin to ground with a small button
 *      press together with other buttons to change lighting scheme
 *    system button + button 1 = reactive lighting
 *    system button + button 3 = HID lighting
 */
 

void doEncL(){
  if((ENCODER_PORT >> ENC_L_B_ADDR)&1){
    encL++;
  } else {
    encL--;
  }
}

void doEncR(){
  if((ENCODER_PORT >> ENC_R_B_ADDR)&1){
    encR++;
  } else {
    encR--;
  }
}

void lights(uint8_t lightDesc){
  for(int i=0;i<buttonCount;i++){
     if((lightDesc>>i)&1){
         digitalWrite(ledPins[i],HIGH);
     } else {
         digitalWrite(ledPins[i],LOW);
     }
  }
}

void setup() {
  delay(1000);
  // Setup I/O for pins
  for(int i=0;i<buttonCount;i++){
    pinMode(buttonPins[i],INPUT_PULLUP);
    pinMode(ledPins[i],OUTPUT);
  }
  pinMode(sysPin,INPUT_PULLUP);
  //setup interrupts
  pinMode(ENC_L_A,INPUT_PULLUP);
  pinMode(ENC_L_B,INPUT_PULLUP);
  pinMode(ENC_R_A,INPUT_PULLUP);
  pinMode(ENC_R_B,INPUT_PULLUP);
  attachInterrupt(digitalPinToInterrupt(ENC_L_A), doEncL, RISING);
  attachInterrupt(digitalPinToInterrupt(ENC_R_A), doEncR, RISING);
}

void loop() {
  // Read buttons
  for(int i=0;i<buttonCount;i++){
    if(digitalRead(buttonPins[i])!=HIGH){
      report.buttons |= (uint16_t)1 << i;
    } else {
      report.buttons &= ~((uint16_t)1 << i);
    }
  }
  // Read Encoders
  report.xAxis = (uint8_t)((int32_t)(encL / ENCODER_SENSITIVITY) % 256);
  report.yAxis = (uint8_t)((int32_t)(encR / ENCODER_SENSITIVITY) % 256);
  // Light LEDs
  if(lightMode==0){
    lights(report.buttons);
  } else {
    lights(iivx_led);
  }
  // Detect Syspin Entries
  if(digitalRead(sysPin)!=HIGH){
    report.buttons = 0;
    for(int i=0;i<4;i++){
      if(digitalRead(sysInputPins[i])!=HIGH){
        report.buttons |= (uint16_t)1 << (i+buttonCount);
      } else {
        report.buttons &= ~((uint16_t)1 << (i+buttonCount));
      }
    }
    if(digitalRead(reactiveLightPin)!=HIGH){
      lightMode = 0;
    } else if (digitalRead(hidLightPin)!=HIGH){
      lightMode = 1;
    }
  }
  // Send report and delay
  iivx.setState(&report);
  delayMicroseconds(REPORT_DELAY);
}

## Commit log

2015-10-23 All buttons working Implementing HID LED functionality
2015-10-23 Working LED descriptor
2015-10-24 add encoder read support
2015-10-26 finish encoders todo: turntable keys turntable
2015-10-28 Add turntable button tolearnce
2015-10-28 Add CAD/SKP files
    [edge.skp, edge.stl, plate.dxf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]
2015-10-29 Add cleaned up + dim'd cad
    [sdvxc2.dwg]
2016-03-28 update, add test/service button
2016-03-30 Add encoder support to /leoo/leovx/, added Encoder library since I can't code encoders for nuts
2016-04-05 add hq encoder
2016-06-14 Fix right encoder in leovxhq
    Was decrementing the left encoder instead of right
    [leovxhq.ino]
2016-09-19 update errors in readme and comments
    [leovx.ino, leovxhq.ino]
2016-12-02 fixed missing bracket
2017-02-18 Fix button 9's HID light
    https://bemaniso.ws/forums.php?action=viewthread&threadid=42319&postid=1303506#post1303506
    Before this fix, all lights except Button 9's work in HID mode. With this fix, all lights including button 9's work. I don't believe this affects IIDX, but this works/fixes pop'n music.
    [leoo.ino]
